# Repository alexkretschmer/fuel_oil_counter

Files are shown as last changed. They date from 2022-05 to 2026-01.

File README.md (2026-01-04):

# Fuel oil counter

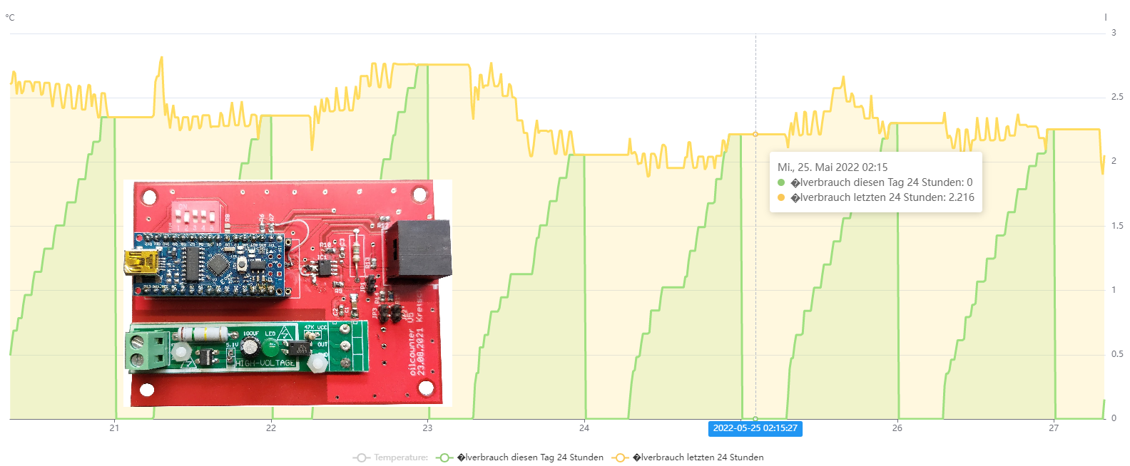
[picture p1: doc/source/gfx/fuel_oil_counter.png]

Fuel oil counter with Modbus (operating hours counters to calculate the fuel oil consumption).
Calculation of the consumption based on the set nozzle liter consumption.

<a href="https://www.buymeacoffee.com/alexkretschmer" target="_blank">
  Buy Me A Coffee
</a>

Full documentation
[Documentation Fuel oil counter](https://alexkretschmer.github.io/fuel_oil_counter/)

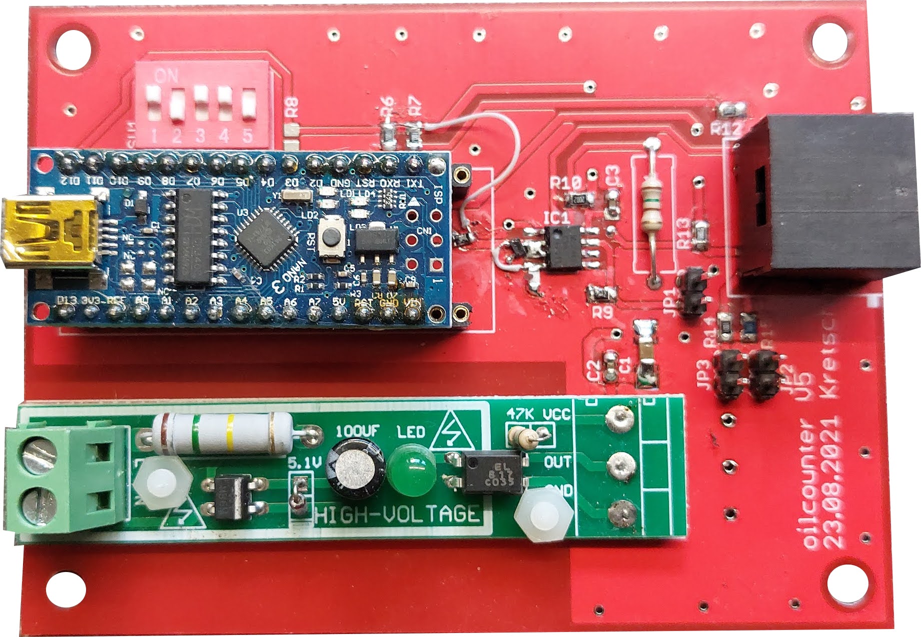
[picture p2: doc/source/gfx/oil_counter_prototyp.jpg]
oil counter prototyp


## Arduino libarys
please add EEPROM and ModbusRtu Libary in the Arduino IDE

## Parameter
operating voltage: 5V
output signal: RS-485
communication protocol: Modbus RTU
communication address: 1 ~ 247 (Standard 1)

## OpenHab example

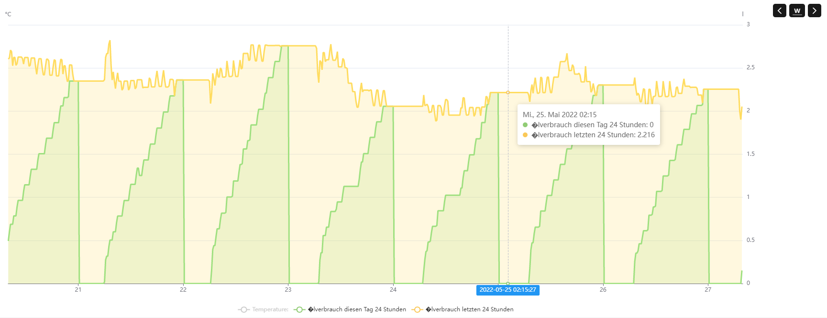
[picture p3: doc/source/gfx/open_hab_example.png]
open_hab_example


openhab examples scripts:[openhab examples](openhab_examples/readme.md)

## programming table SW1

The factor for the calculation of the heating oil is set with the dip switch SW1.

| 1 | 2 | 3 | 4 | 5 | oil kg per hour|
|:---:|:---:|:---:|:---:|:---:|:---:|
| off | off | off | off | off | 1.45 |
| off | off | off | off | on  | 1.5 |
| off | off | off | on  | off | 1.55 |
| off | off | off | on  | on  | 1.6 |
| off | off | on  | off | off | 1.65 |
| off | off | on  | off | on  | 1.7 |
| off | off | on  | on  | off | 1.75 |
| off | off | on  | on  | on  | 1.8 |
| off | on  | off | off | off | 1.85 |
| off | on  | off | off | on  | 1.9 |
| off | on  | off | on  | off | 1.95 |
| off | on  | off | on  | on  | 2 |
| off | on  | on  | off | off | 2.05 |
| off | on  | on  | off | on  | 2.1 |
| off | on  | on  | on  | off | 2.15 |
| off | on  | on  | on  | on  | 2.2 |
| on  | off | off | off | off | 2.25 |
| on  | off | off | off | on  | 2.3 |
| on  | off | off | on  | off | 2.35 |
| on  | off | off | on  | on  | 2.4 |
| on  | off | on  | off | off | 2.45 |
| on  | off | on  | off | on  | 2.5 |
| on  | off | on  | on  | off | 2.55 |
| on  | off | on  | on  | on  | 2.6 |
| on  | on  | off | off | off | 2.65 |
| on  | on  | off | off | on  | 2.7 |
| on  | on  | off | on  | off | 2.75 |
| on  | on  | off | on  | on  | 2.8 |
| on  | on  | on  | off | off | 2.85 |
| on  | on  | on  | off | on  | 2.9 |
| on  | on  | on  | on  | off | 2.95 |
| on  | on  | on  | on  | on  | 3 |

## Modbus Protocol
### Function codes
        
|command register| function |
|---|---|
| 0x03 | read keep register |
| 0x04 | read input register |
| 0x06 | write a single register |
| 0x10 | write more keep registers |

### Registers

|regsiter type | register address | gegister contents | bytes | register - ID  |
|---|---|---|---|---|
| input register | 0x0001 | ml summary Hi Byte  | 2 |  1 | 
| input register | 0x0002 | ml summary Low Byte | 2 |  2 | 
| input register | 0x0003 | s summary Hi Byte | 2 |  3 | 
| input register | 0x0004 | s summary Low Byte  | 2 |  4 | 
| input register | 0x0005 | ms time Hi Byte | 2 |  5 | 
| input register | 0x0006 | ms time Low Byte  | 2 |  6 |
| input register | 0x0007 | l summary | 2 |  7 (EEPROM) |
| input register | 0x0008 | h active summary | 2 |  8 (EEPROM) |
| debug register | 0x0009 | DIP value | 2 |  9 |
| debug register | 0x0010 | gram per hour | 2 |  10 |
| debug register | 0x0011 | ml per hour | 2 |  11 |
| debug register | 0x0012 | fw version | 2 |  12 |
| keep register  | 0x0013 | device address | 2 |  13 (EEPROM) |
| keep register  | 0x0014 | baud rate | 2 |  14 (EEPROM) |
| keep register  | 0x0015 | reset summary | 2 |  15 |

baudrate = 0 =>  9600 baud
           1 => 14400 baud
           2 => 19200 baud

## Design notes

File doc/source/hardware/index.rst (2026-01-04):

Hardware
========

The installation of the heating oil counter follows the same logic as a traditional **operating hours meter** (hour meter). 

Instead of measuring the oil flow directly with a mechanical turbine, this device is connected to the **oil burner's 230V signal line** (typically the "B4" signal on standard burner plugs). 

Fuel oil counter with Modbus (operating hours counters to calculate the fuel oil consumption). Calculation of the consumption based on the set nozzle liter consumption.

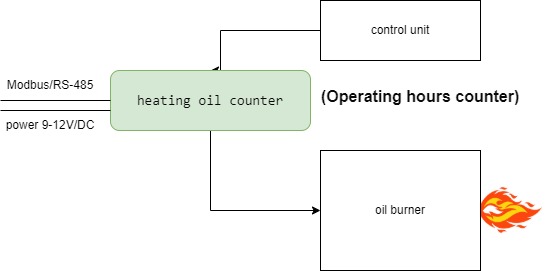
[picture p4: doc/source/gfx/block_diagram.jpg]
block diagram


**How it works:**
*   **Signal Detection:** The counter detects when the burner is active.
*   **Calculation:** By knowing the specific nozzle throughput (gallons/liters per hour) and the measured burner runtime, the system calculates the consumed fuel with high precision.
*   **Safety:** This non-invasive method is preferred as it does not require breaking into the oil lines, significantly reducing the risk of leaks.

Connectivity
--------------

In addition to the burner signal detection, the counter is integrated into your network via **Modbus**. 

*   **Data Transmission:** The device must be connected via the Modbus interface to a separate PC, a Raspberry Pi, or directly to a **Home Assistant** instance.

.. important::
   Ensure that your Modbus gateway (e.g., USB-to-RS485 adapter) is correctly configured to communicate with the counter's registers.

Safety Warning
--------------

.. warning::
   **DANGER: 230V AC MAINS VOLTAGE!**
   
   The connection to the burner signal involves working with 230V AC electricity. 
   
   *   **Disconnect Power:** Always disconnect the heating system from the main power supply before opening any covers or touching wires.
   *   **Professional Installation:** Electrical work should only be performed by qualified personnel. 
   *   **Risk of Death:** Improper handling of mains voltage poses a serious risk of electric shock or fire.

Prototyp
---------------------

Alternativtext für das Bild

Click for downloads:

 :download:`Layout download <../../../pcb/prototyp_v10/fuil_oil_counter.brd>`.
 :download:`Shematic download <../../../pcb/prototyp_v10/fuil_oil_counter.sch>`.

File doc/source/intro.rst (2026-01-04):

Project: Digital Heating Oil Counter
====================================

Welcome to the official documentation of the Heating Oil Counter project.

This project focuses on the development and construction of a precise, DIY-based measuring system to monitor heating oil consumption. In an era of rising energy costs and the growing need for household transparency, this system provides a cost-effective solution to digitally track current fuel levels and daily consumption.

Project Objectives
------------------

The primary goal of this project is to move away from manual estimations and mechanical gauges toward a data-driven monitoring approach. 

Key features of the system include:

*   **Real-time Tracking:** Monitoring the actual flow rate during burner operation.
*   **Consumption Analysis:** Calculating usage patterns over various periods (day, month, year).
*   **Smart Home Integration:** Connectivity with systems such as Home Assistant via Modbus.

Why this Project?
-----------------

Traditional mechanical counters are often imprecise or lack remote reading capabilities. This heating oil counter bridges that gap by combining modern sensor technology with a user-friendly digital interface. It empowers you to keep full control over your heating expenses—directly from your smartphone or computer.

.. note::
   This project is under active development. Feedback and contributions via the GitHub repository are always welcome.

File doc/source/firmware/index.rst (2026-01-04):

Firmware
========

Please add EEPROM and ModbusRtu Libary in the Arduino IDE.

prototyp firmware:
-------------------

 :download:`fuel_oil_counter zip-file download </download/fuel_oil_counter.zip>`.

parameter
-------------
operating voltage: 5V output signal: RS-485 communication protocol: Modbus RTU communication address: 1 ~ 247 (Standard 1)

programming table SW1
------------------------

The factor for the calculation of the heating oil is set with the dip switch SW1.

.. csv-table:: DIP Switch SW1
   :file: /table/SW1.csv
   :header-rows: 1
   :widths: auto

Modbus Protocol
------------------
Function codes
~~~~~~~~~~~~~~~~~~
.. csv-table:: Function Codes
   :file: /table/function_codes.csv
   :header-rows: 1
   :widths: auto 

Registers
~~~~~~~~~~~~~~~~~~

.. csv-table:: register
   :file: /table/register.csv
   :header-rows: 1
   :widths: auto 

Baudrates / parameter
~~~~~~~~~~~~~~~~~~~~~~~~~

* 0 =>  9600 baud
* 1 => 14400 baud
* 2 => 19200 baud

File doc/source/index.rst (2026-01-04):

Fuel Oil Counter 
=================

Alternativtext für das Bild

If you like my work, feel free to

Buy Me A Coffee

.. toctree::
   :maxdepth: 2
   :caption: Contents:

   intro

.. toctree::
   :maxdepth: 2
   :caption: Technical Documentation:

   hardware/index
   firmware/index
   example/index

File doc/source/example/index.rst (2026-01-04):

Example for Openhab
====================

I've managed to get my oil meter into openHAB. The integration is a bit of a workaround and not yet ideal, but it’s functional for the time being.

Example for my openhab rule:

.. literalinclude:: modbus.rules
   :language: shell
   :linenos:

Example for my openhab things:

.. literalinclude:: modbus.things
   :language: shell
   :linenos:

Example for my openhab items:

.. literalinclude:: modbus.items
   :language: shell
   :linenos:

The integrated data can then be displayed on any openHAB dashboard, providing a clear overview of the remaining oil and heating trends.

openhab example

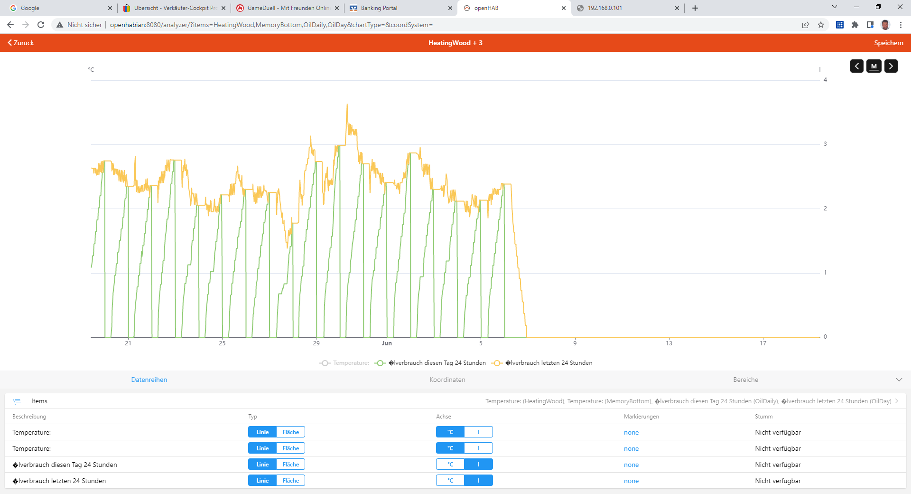
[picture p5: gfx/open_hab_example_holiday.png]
openhab example


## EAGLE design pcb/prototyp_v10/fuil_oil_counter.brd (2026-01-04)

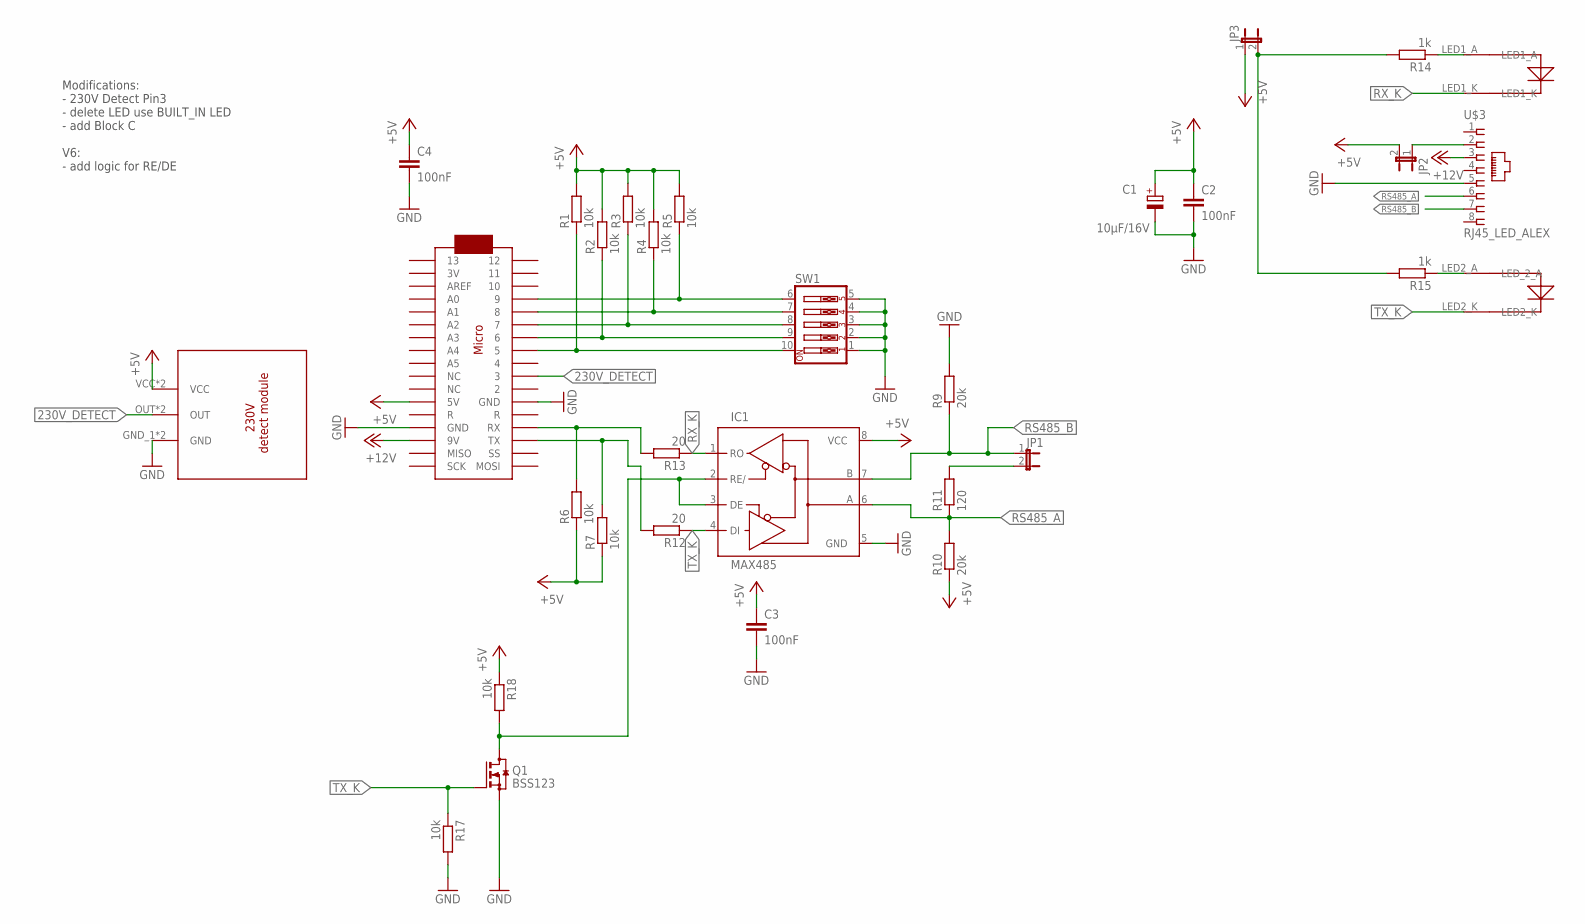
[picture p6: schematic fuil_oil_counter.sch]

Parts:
C1: 10µF/16V; SMC_C
C2, C3, C4: 100nF; C0805
IC1: MAX485; SO08
JP1, JP2, JP3: JP1E; JP1
Q1: BSS123; SOT23
R1, R2, R3, R4, R5, R6, R7, R17, R18: 10k; M0805
R9, R10: 20k; M0805
R11: 120; P0613/15
R12, R13: 20; M0805
R14, R15: 1k; M0805
SW1: SW_DIP-5; EDG-05
U$1: ARDUINOMICRO
U$2: POWER_DETECT
U$3: RJ45_LED_ALEX; RJ45-NO-SHIELD-WITH_LED

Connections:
230V_DETECT: U$1.P$10 (3), U$2.OUT, U$2.OUT_2 (OUT)
+5V: C1.+, C2.1, C3.1, C4.1, IC1.8 (VCC), JP2.2, JP3.1, R1.2, R2.2, R3.2, R4.2, R5.2, R6.1, R7.1, R10.1, R18.1, U$1.P$23 (5V), U$2.VCC, U$2.VCC_2 (VCC)
+12V: U$1.P$20 (9V), U$3.3
EN: IC1.2 (RE/), IC1.3 (DE), Q1.3 (D), R18.2
GND: C1.-, C2.2, C3.2, C4.2, IC1.5 (GND), Q1.2 (S), R9.2, R17.2, SW1.1, SW1.2, SW1.3, SW1.4, SW1.5, U$1.P$12 (GND), U$1.P$21 (GND), U$2.GND_1 (GND), U$2.GND_PIN (GND), U$3.5
unnamed: R1.1, SW1.10, U$1.P$8 (5)
unnamed: R2.1, SW1.9, U$1.P$7 (6)
unnamed: R3.1, SW1.8, U$1.P$6 (7)
unnamed: R4.1, SW1.7, U$1.P$5 (8)
unnamed: R5.1, SW1.6, U$1.P$4 (9)
unnamed: JP2.1, U$3.2
unnamed: JP1.2, R11.2
unnamed: R14.1, U$3.LED1_A
unnamed: R15.1, U$3.LED2_A (LED_2_A)
unnamed: R6.2, R13.2, U$1.P$14 (RX)
unnamed: R7.2, R12.2, U$1.P$15 (TX)
unnamed: JP3.2, R14.2, R15.2
RS485_A: IC1.6 (A), R10.2, R11.1, U$3.6
RS485_B: IC1.7 (B), JP1.1, R9.1, U$3.7
RX_K: IC1.1 (RO), R13.1, U$3.LED1_K
TX_K: IC1.4 (DI), Q1.1 (G), R12.1, R17.1, U$3.LED2_K

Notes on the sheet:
Modifications: - 230V Detect Pin3 - delete LED use BUILT_IN LED - add Block C V6: - add logic for RE/DE

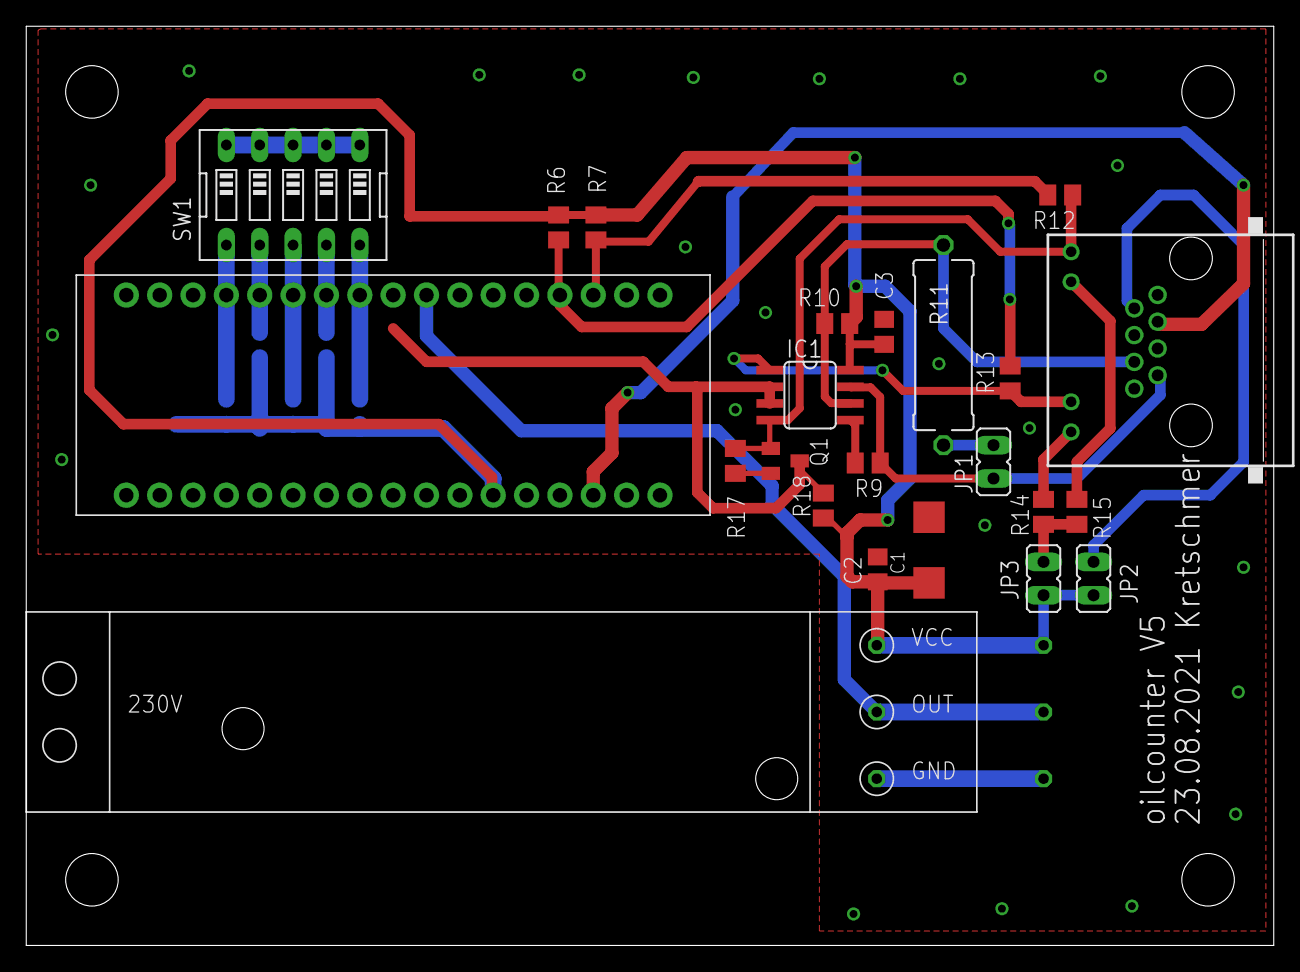
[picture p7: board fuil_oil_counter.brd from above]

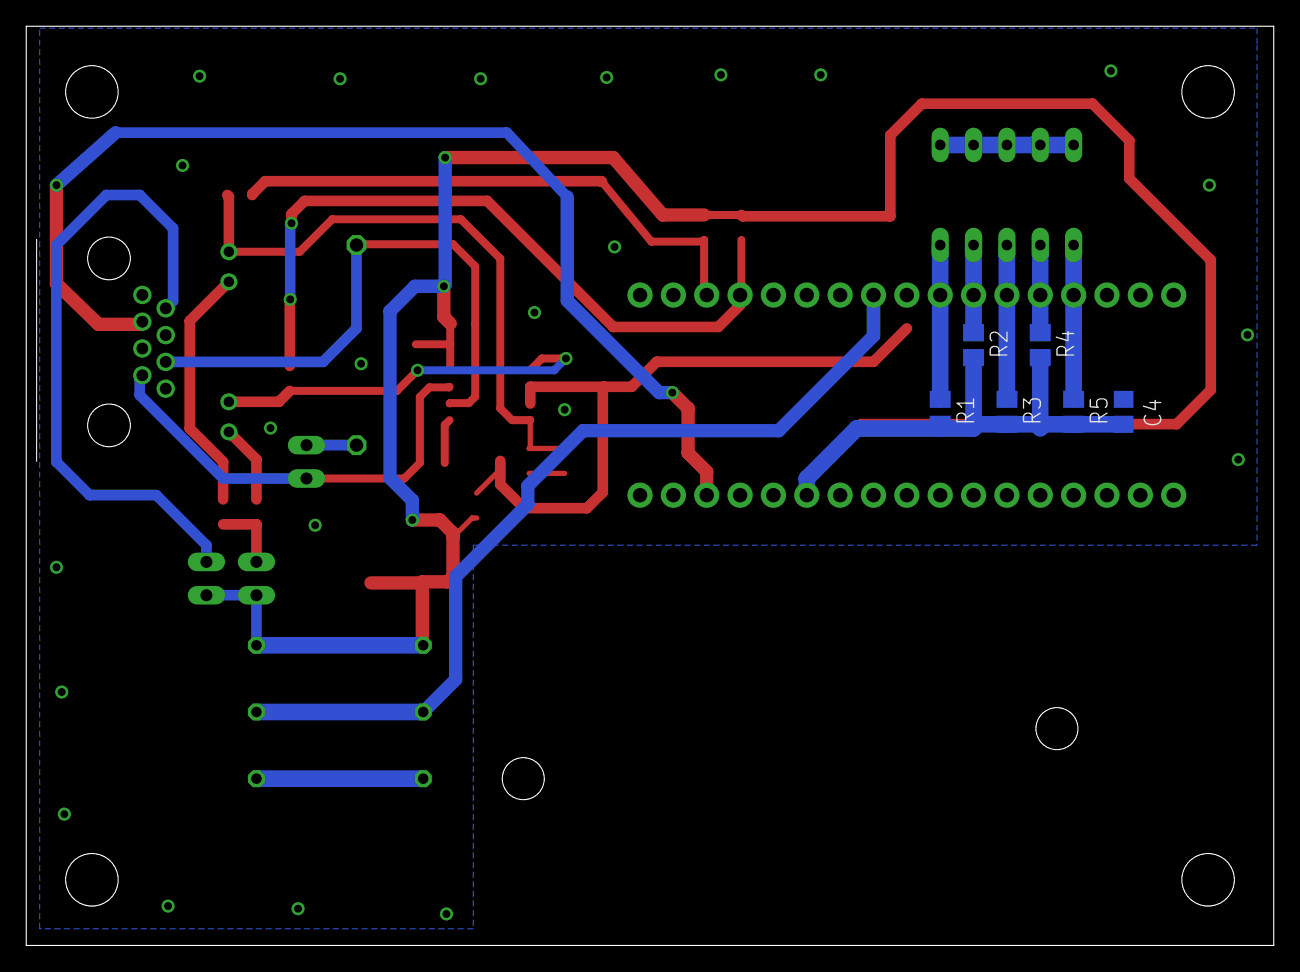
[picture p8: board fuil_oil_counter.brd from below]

Board: 2 copper layers, 95.0 x 70.0 mm, 29 parts (6 on the bottom side), 21 nets.

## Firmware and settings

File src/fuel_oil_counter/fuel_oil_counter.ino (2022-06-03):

/* heatoilcounter
 * 17.02.2021 Alexander Kretschmer
 * BOARD Arduino nano
 * Prozessor ATmega168
 */

#include "dip_mode.h"
#include <EEPROM.h>
#include "counter.h"
#include<ModbusRtu.h>       //Library for using Modbus in Arduino

#define fw_version 10
#define inPowerDetect 3     // pin 2 problem ??
#define ledPower 13

#define Rg_ml_summary_hi 1
#define Rg_ml_summary_low 2
#define Rg_s_summary_hi 3
#define Rg_s_summary_low 4
#define Rg_time_hi 5
#define Rg_time_low 6
#define Rg_l_summary 7
#define Rg_h_active_summary 8
#define Rg_DIP 9
#define Rg_g_per_hour 10
#define Rg_ml_per_hour 11
#define Rg_fw_version 12
#define Rg_Device_address 13
#define Rg_Baud_rate 14
#define Rg_Reset_summary 15


#define sumDIP 5
#define DIP1 5
#define DIP2 6
#define DIP3 7
#define DIP4 8
#define DIP5 9

const int inputs[sumDIP] = {DIP1,DIP2,DIP3,DIP4,DIP5};
dip DIP(sumDIP,inputs);

unsigned int g_per_hour;
unsigned int ml_per_hour;
unsigned int ul_per_second;

unsigned int currentActiveSeconds;

unsigned long summaryMl;
unsigned long summarySeconds;
unsigned int Device_address;
unsigned int baudrate;



Modbus bus;                          //Define Object bus for class modbus 
// Modbus register data array (start register = 0)
uint16_t au16data[22] = {0, 0, 0, 0, 0, 0, 0, 0, 0, 0, 0, 0, 0, 0, 0, 0,0,0,0,0,0,0}; // 20 registers


Counter counter(inPowerDetect,ledPower );

void saveConfig() {
  int address = 0; // EEPROM starting address
  // Save configuration from RAM into EEPROM
  EEPROM.begin();
    EEPROM.put(address, counter.sumMl);
    address = address + 4;
    delay(200);
   EEPROM.put(address, counter.sumSec);
    address = address + 4;
        delay(200);
   EEPROM.put(address, Device_address);
    address = address + 2;
   EEPROM.put(address, baudrate);
    address = address + 2;
    
    delay(200);

  EEPROM.end();                         // Free RAM copy of structure
}

void loadConfig() {
  int address = 0; // EEPROM starting address
  // Loads configuration from EEPROM into RAM
  EEPROM.begin();
    EEPROM.get(address, counter.sumMl);
    address = address +4;
    EEPROM.get(address, counter.sumSec);
    address = address +4;
    EEPROM.get(address, Device_address);
    address = address +2;
    if (Device_address==0)
    {
      Device_address=1;
    }
    EEPROM.get(address, baudrate);
    address = address +2;
    if (baudrate>3)
    {
      baudrate = 0;
    }
    

  EEPROM.end();
}



void setup() 
{
  pinMode(4,OUTPUT); //TEST
  digitalWrite(4,LOW); //TEST
  loadConfig();
  bus = Modbus(Device_address,1,4);            //Modbus slave ID as 1 and 1 connected via RS-485 and 4 connected to DE & RE pin of RS-485 Module 
  if (baudrate==2)bus.begin(19200);                //Modbus slave baudrate at 9600
  else if (baudrate==1)bus.begin(14400); 
  else bus.begin(9600); 

  g_per_hour = DIP.value*50 + 1450;     //calculation gramm per hour
  ml_per_hour = (g_per_hour*10/86)*10;  //calculation mililiter per hour
  ul_per_second = ml_per_hour*10/36;    //Calculation uliter per second

 // init values
  counter.ulSec = ul_per_second;   

  au16data[Rg_DIP] = DIP.value;
  au16data[Rg_g_per_hour] = g_per_hour;
  au16data[Rg_ml_per_hour] = ml_per_hour;
  au16data[Rg_fw_version] = fw_version;
  au16data[Rg_h_active_summary] = counter.sumSec/3600;
  au16data[Rg_l_summary] = counter.sumMl/1000;
  au16data[Rg_ml_summary_low]= counter.sumMl;
  au16data[Rg_ml_summary_hi]= counter.sumMl>>16;
  au16data[Rg_Device_address] = Device_address;
  au16data[Rg_s_summary_low]=counter.sumSec;
  au16data[Rg_s_summary_hi]=counter.sumSec>>16;
  
}

void loop() {

  //  Mbus - Commands
  bus.poll(au16data,sizeof(au16data)/sizeof(au16data[0]));       //Used to receive or write value from Master 
  if (au16data[Rg_Reset_summary] == 0xAFFE)            // Reset summary values
  {
    // Reset Values
    counter.sumSec = 0;
    counter.sumMl = 0;
    saveConfig();
    au16data[Rg_h_active_summary] = 0;
    au16data[Rg_l_summary] = 0;
    au16data[Rg_ml_summary_low]= 0;
    au16data[Rg_ml_summary_hi]= 0;
    au16data[Rg_Reset_summary]=0x321;
  }
  if (au16data[Rg_Device_address]!=Device_address)     // new configuration Device Address
  {
    Device_address = au16data[Rg_Device_address];
    saveConfig();
  }
  if (au16data[Rg_Baud_rate]!=baudrate)                  // new configuration baudrate
  {
    baudrate = au16data[Rg_Baud_rate];
    saveConfig();
  }

  // Counter
  int calc = counter.Update(); 
  if (calc!=0)
  {
    au16data[Rg_l_summary] = counter.sumMl/1000;
    au16data[Rg_h_active_summary] = counter.sumSec/3600;
    au16data[Rg_ml_summary_low]= counter.sumMl;
    au16data[Rg_ml_summary_hi]= counter.sumMl>>16;
    au16data[Rg_s_summary_low]=counter.sumSec;
    au16data[Rg_s_summary_hi]=counter.sumSec>>16;
  }
    au16data[Rg_time_low]=counter.timeMillis;
    au16data[Rg_time_hi]=counter.timeMillis>>16;
  if (calc>2){
    saveConfig();
  }
  delay(200); 
}

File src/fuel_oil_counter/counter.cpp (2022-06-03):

/*
  counter.cpp 
  calculation heatoil 
  
*/

#include "Arduino.h"
#include "counter.h"


#define seconds() (MyMillis()/1000)
#define HourMillis 3600000
#define OverflowLimit 4233605000

unsigned long MMdelta = 0; //0xFFE488BF;   //30min befor overflow
void(* resetFunc) (void) = 0; //declare reset function @ address 0

unsigned long MyMillis()
{
 return millis()+ MMdelta;
}



Counter::Counter(int inPin,int LED) // Init sequence
{
  _inPin = inPin;
  _led = LED;
  
  // initialize the LED pin as an output:
  pinMode(LED, OUTPUT);
  // initialize the pushbutton pin as an input:
  pinMode(_inPin, INPUT_PULLUP);
  currActSec=0;
  _nextHour = HourMillis;
  active=false;
  _newPulse=false;
}


int Counter::Update (void)
  {
    //***************************
    // Update
    // return 0 = no clac
    //        1 = normal calc
    //        2 = next  hour with pulse
    //        3 = next hour without pulse
    //****************************
    unsigned long tempMlSummary;
    unsigned long diffTime;
    int tmpReturn=0;
    active = !digitalRead(_inPin);   //inverted module
      
    
    if(active && !_oldActive){
       _startTime = MyMillis();
       _newPulse = true;
       digitalWrite(_led,true);
    }
    else if(!active && _oldActive)
    {
      _stopTime = MyMillis();
      digitalWrite(_led,false);
    }
     _oldActive = active;
    
     if (MyMillis()>_nextHour){    // NEW HOUR
        tmpReturn = 3; // detection for Save Data in EEPROM
        _nextHour = _nextHour + HourMillis;
        if(active){
        tmpReturn = 2;
       _stopTime = MyMillis();   // simulation new value
        active = false;
        _newPulse = true;

        }
     }
     if (!active&&_newPulse)    //calc
     {
        if(tmpReturn==0)tmpReturn=1;
        diffTime = _stopTime - _startTime;         // diff time impuls length
        _addTimeSekunde = diffTime/1000; 
        sumSec = sumSec + _addTimeSekunde;          // New Sec Summary
        
        tempMlSummary = _addTimeSekunde;
        tempMlSummary = tempMlSummary * ulSec;
        tempMlSummary = tempMlSummary /1000;
        sumMl = tempMlSummary + sumMl;      //NEW Ml Summary
        _newPulse = false;

     }
     if (tmpReturn == 2){
        _startTime = _stopTime;   // simulation new value
        active = true;
     }
        timeMillis = MyMillis();   // simulation new value

     if (OverflowLimit<MyMillis())
     {
        resetFunc();  //call reset
     }
     return tmpReturn;
   }

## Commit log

2022-05-27 modify readme and add pcb layout
    [fuil_oil_counter.brd, fuil_oil_counter.sch]
2022-05-27 add programming table , moidfy pcb
2026-01-04 add some documentation
    [SW1.csv, fuil_oil_counter.brd, fuil_oil_counter.sch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]
